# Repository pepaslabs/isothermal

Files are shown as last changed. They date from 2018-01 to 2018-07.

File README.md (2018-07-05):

# isothermal

An Arduino shield which regulates temperature.  Originally, this was used to regulate the temperature of a Hammond 1590BB.

- [schematic](kicad/releases/v1.2/isothermal.pdf)
- [gerber files](kicad/releases/v1.2)
- [OSHPark link](https://oshpark.com/shared_projects/9wWvXwMw)
- [EEVBlog discussion](http://www.eevblog.com/forum/metrology/temperature-stabilised-enclosures-heating-and-or-cooling/msg1407134/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)

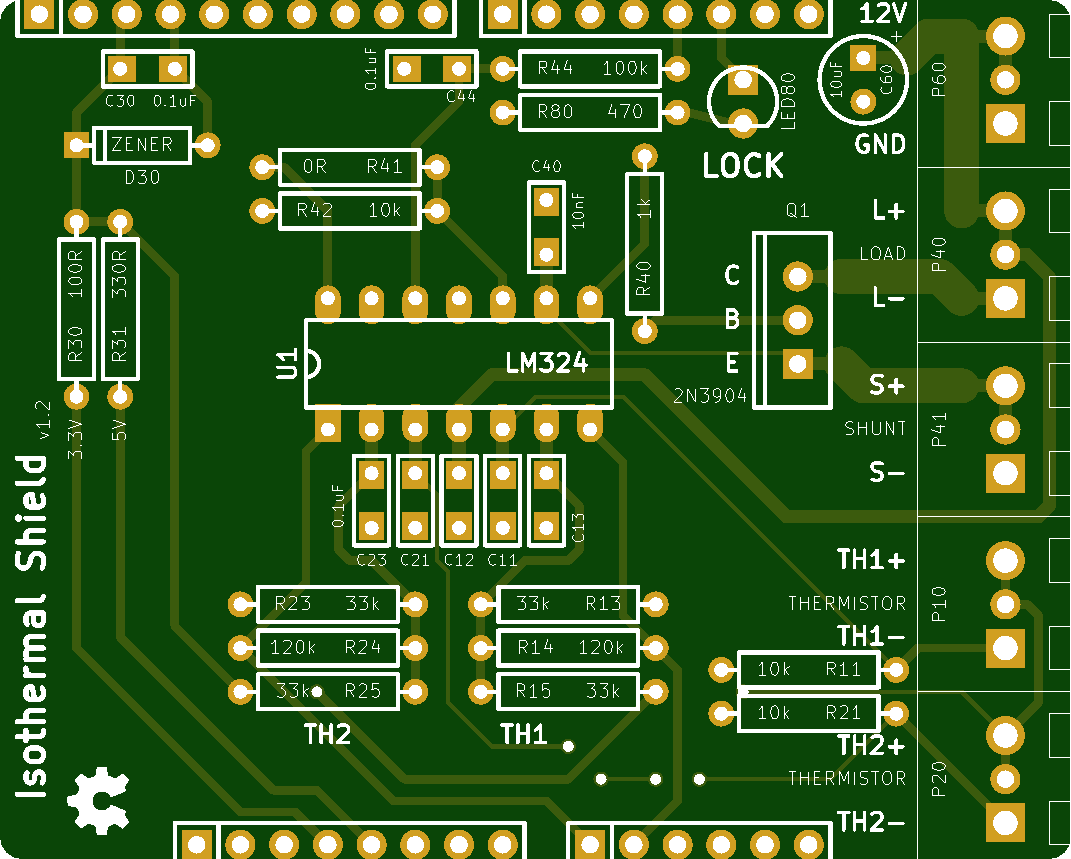
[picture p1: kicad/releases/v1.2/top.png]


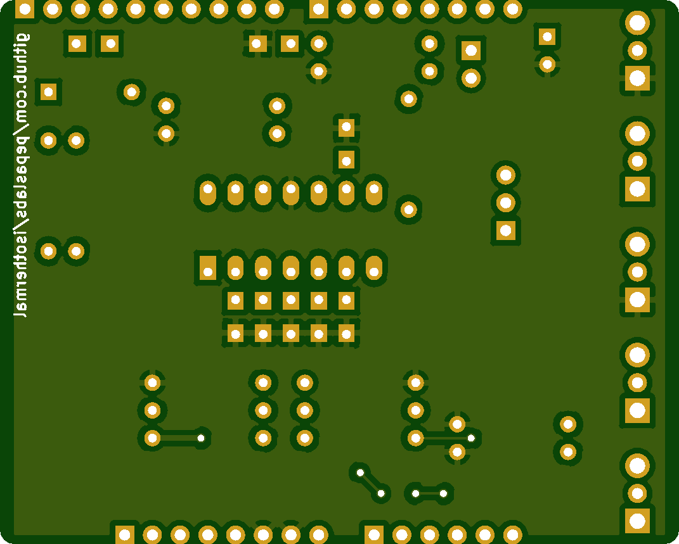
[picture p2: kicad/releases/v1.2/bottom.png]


The resistor values were chosen to map a 20C to 30C window onto (roughly) 0V to 3.3V.

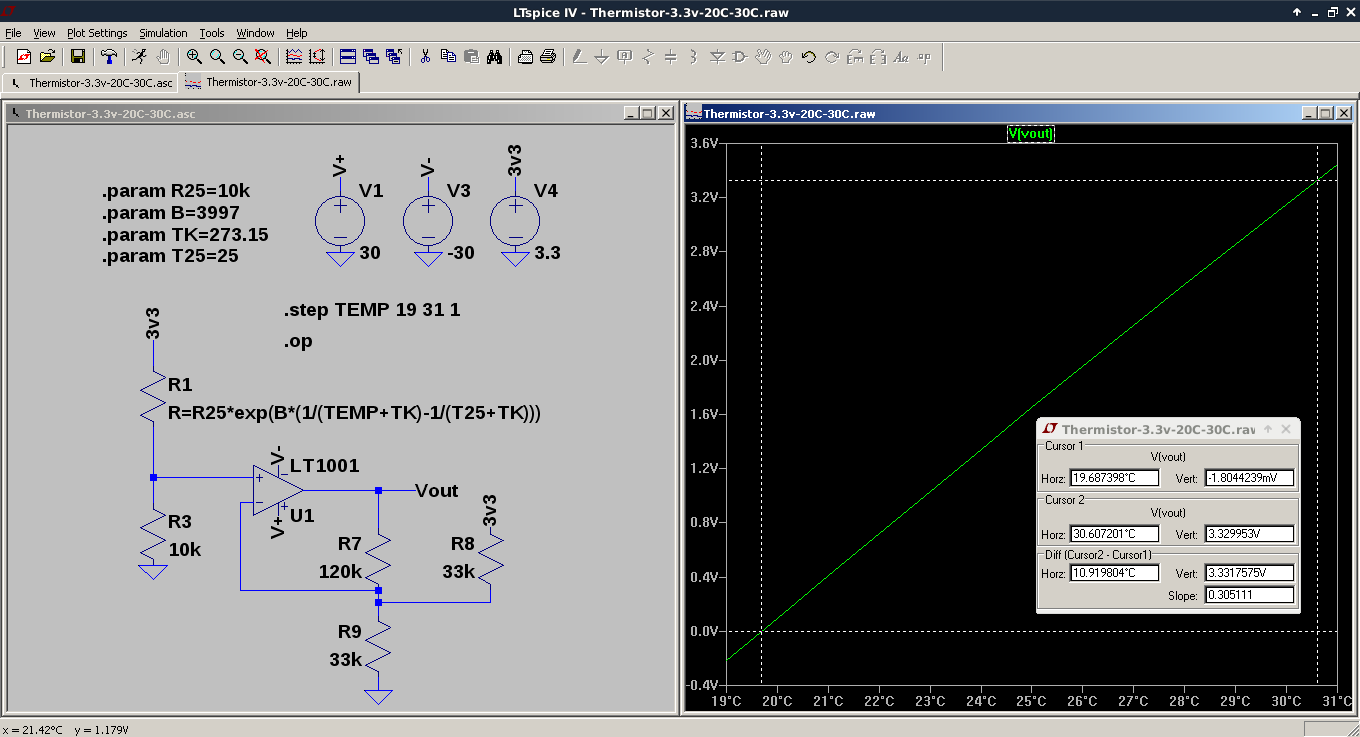
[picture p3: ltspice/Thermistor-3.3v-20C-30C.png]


See also [this link](https://github.com/cellularmitosis/logs/tree/master/20180126-25c-chamber-tuning) for PID tuning and measurements of a similar design (based on MCP9701 rather than thermistors).

## Bill of Materials (BOM)

FIXME: update this BOM for v1.2.

- (1) LM324 op amp, DIP14.
  - [Tayda](https://www.taydaelectronics.com/lm324n-lm324-324-low-power-quad-op-amp-ic.html).
- (1) 2N3904 TO-92 NPN transistor.
  - Almost any TO-92 transistor should work here.
  - [Tayda](https://www.taydaelectronics.com/t-transistors/2n-series/2n3904-npn-general-propose-transistor.html).
  - The footprint is for a TO-220, in case you need to use a bigger transistor.
- (2) 10k thermistors.
  - I use Vishay [NTCLG100E2103JB](http://www.vishay.com/docs/29050/ntclg100.pdf) which are about $1 each from [Digi-key](https://www.digikey.com/product-detail/en/vishay-bc-components/NTCLG100E2103JB/BC2531-ND/773999).
  - You could also get away with [cheap epoxy bead thermistors](https://www.taydaelectronics.com/thermistors/10k-ohm-ntc-thermistor-5mm.html), though if the Beta is different you'll need to calibrate the gain of your controller.
- 1/4W resistors, 1% metal film (precision-ish):
  - (2) 10k.
  - (4) 33k.
  - (2) 120k.
  - [Tayda](https://www.taydaelectronics.com/resistors/1-4w-metal-film-resistors/test-group-2.html).
- 1/4W resistors (non-precision):
  - (1) 100R
  - (1) 470R
    - The LED resistor -- 330R or 220R will also work.
  - (1) 1k
  - (4) 100k
  - [Tayda](https://www.taydaelectronics.com/resistors/1-4w-metal-film-resistors/test-group-2.html).
- (9) 0.1uF ceramic capacitors, through-hole or 0805.
  - [Tayda](https://www.taydaelectronics.com/capacitors/ceramic-disc-capacitors/10-x-0-01uf-50v-ceramic-disc-capacitor-pkg-of-10.html).
- (1) 10uF electrolytic capacitor, 25V, 5mm diameter, 0.1" (2.5mm) lead spacing.
  - [Tayda](https://www.taydaelectronics.com/capacitors/electrolytic-capacitors/10uf-25v-105c-radial-electrolytic-capacitor-5x11mm.html).
- (1) 3mm LED.
  - [Tayda](https://www.taydaelectronics.com/led-3mm-green.html).
- (4) 2-pole terminal block, linkable, 0.2" lead spacing.
  - [Digi-key](https://www.digikey.com/product-detail/en/on-shore-technology-inc/OSTTA024163/ED2580-ND/614529).
  - Note: don't get the cheap (ebay) ones with the phillips-head screws -- the screws are garbage and the heads will strip.  If you go cheap, get the flat-head screws.  I ordered these and they seem to do the job: https://www.ebay.com/itm/182525842695
  - I'm not sure the [Tayda](https://www.taydaelectronics.com/connectors-sockets/terminal-blocks/pcb-mount/dg300-screw-terminal-block-2-positions-5mm.html) parts will work, as they are 5mm spacing, rather than 5.08mm, which might be a problem when you link 4 of them together and expect them to fit into 0.2" holes.
- 0.1" male headers: a block of 10, 8, 8, and 6.
  - These are the Arduino pins.
  - Actually, you only need 10 pins: 3.3V, 5V, GND, GND, A0, A1, AREF, AREF's GND, D3, D2.

If you are using this to heat a Hammon 1590BB, you'll also need:
- (1) Hammond 1590BB Aluminum enclosure.
  - [Tayda](https://www.taydaelectronics.com/hardware/enclosures/1590bb-style/1590bb-style-aluminum-diecast-enclosure.html).
- 1/2W or 1W (heater) resistors.
  - (10) 10R
    - [Tayda](https://www.taydaelectronics.com/resistors/1w-metal-film-resistors/resistor-10-ohm-1w-1-metal-film-pkg-of-10.html).
- Some thermal epoxy.  Arctic Silver is easy to source.  [Walmart](https://www.walmart.com/ip/Arctic-Silver-Alumina-Premium-Ceramic-Thermal-Adhesive/20449152) has it for $6 at the moment.
- (2) "craft foam" (9x12 sheets, 6mm)
  - [Amazon](https://www.amazon.com/Bulk-Buy-Foamies-10-Pack-1199-21/dp/B00KDMQB4Y).
- Hot glue to secure the foam to the Hammond case.
- Very thin gauge wire to connect the remote thermistor.  Scrap Ethernet twisted pairs will work (26 AWG), but 30 AWG "Kynar" (wire-wrap) wire is better (less error due to heat transfer along the wire).  Thin-gauge "magnet" wire will also work.
- An Arduino.

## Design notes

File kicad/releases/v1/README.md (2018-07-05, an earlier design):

## Deprecated

Don't use this version of the board.  Use [v1.1](../v1.1) instead.

I made the spacing on the arduino pin headers a little too tight, and the holes for the terminal blocks aren't big enough to accomodate some terminal blocks.

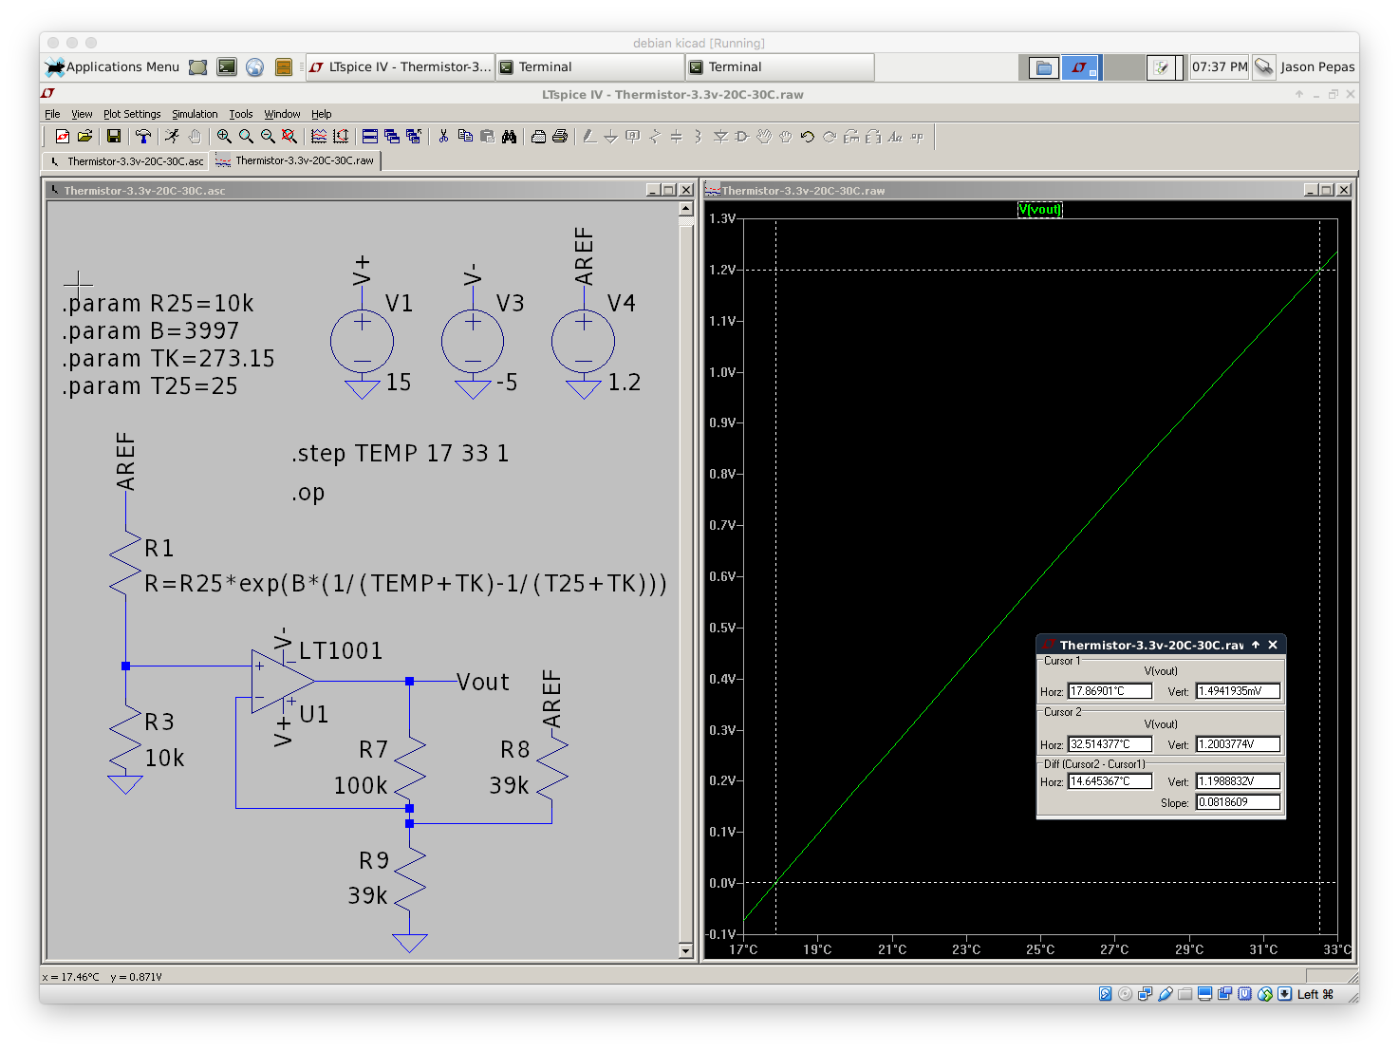
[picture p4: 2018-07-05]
ltspice/100k/scale/18C-32C-100k-39k-39k.png

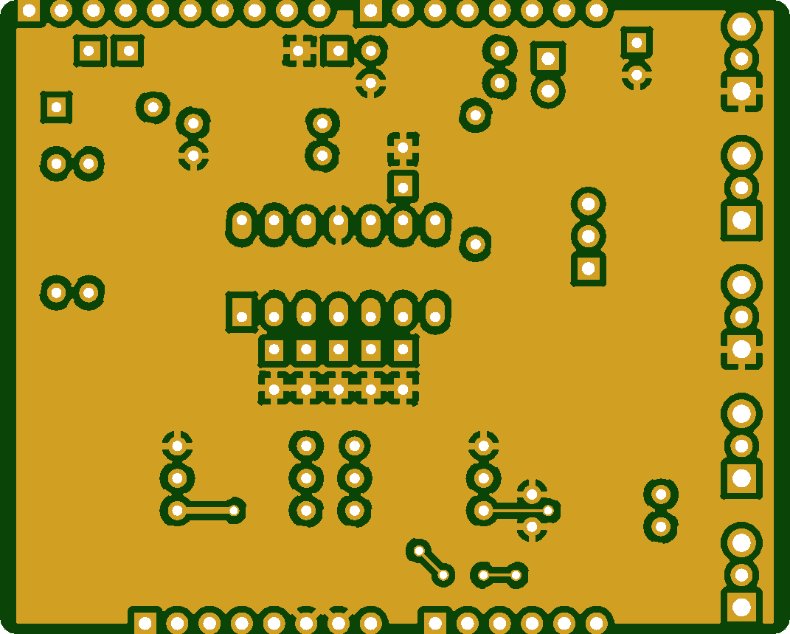
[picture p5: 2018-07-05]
kicad/releases/v1.2/bottom-copper.png

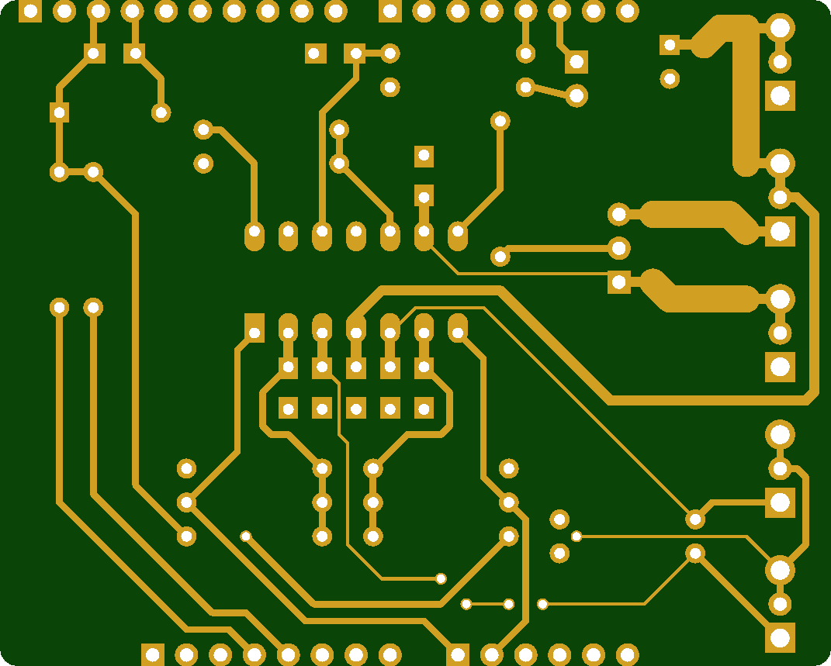
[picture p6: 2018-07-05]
kicad/releases/v1.2/top-copper.png

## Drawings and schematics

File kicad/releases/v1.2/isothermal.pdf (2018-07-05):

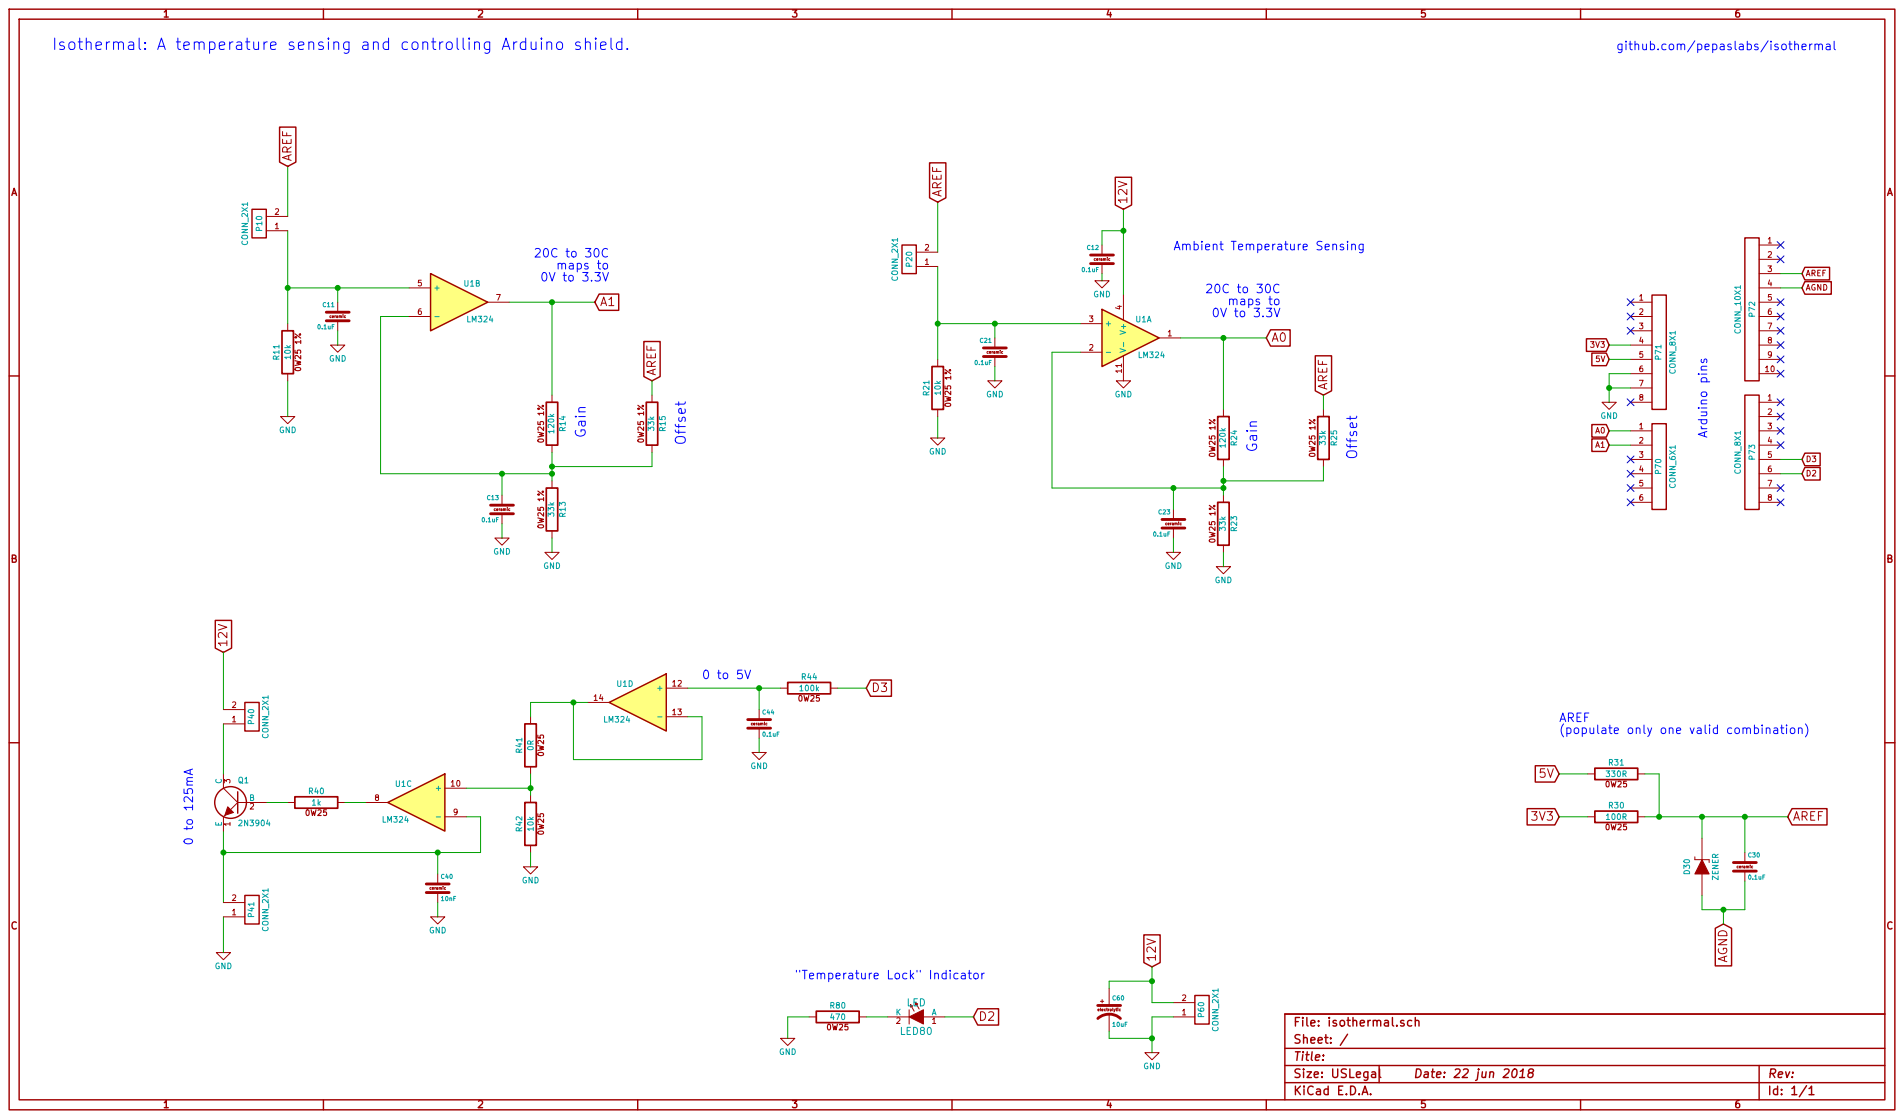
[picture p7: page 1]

(populate only one valid combination)

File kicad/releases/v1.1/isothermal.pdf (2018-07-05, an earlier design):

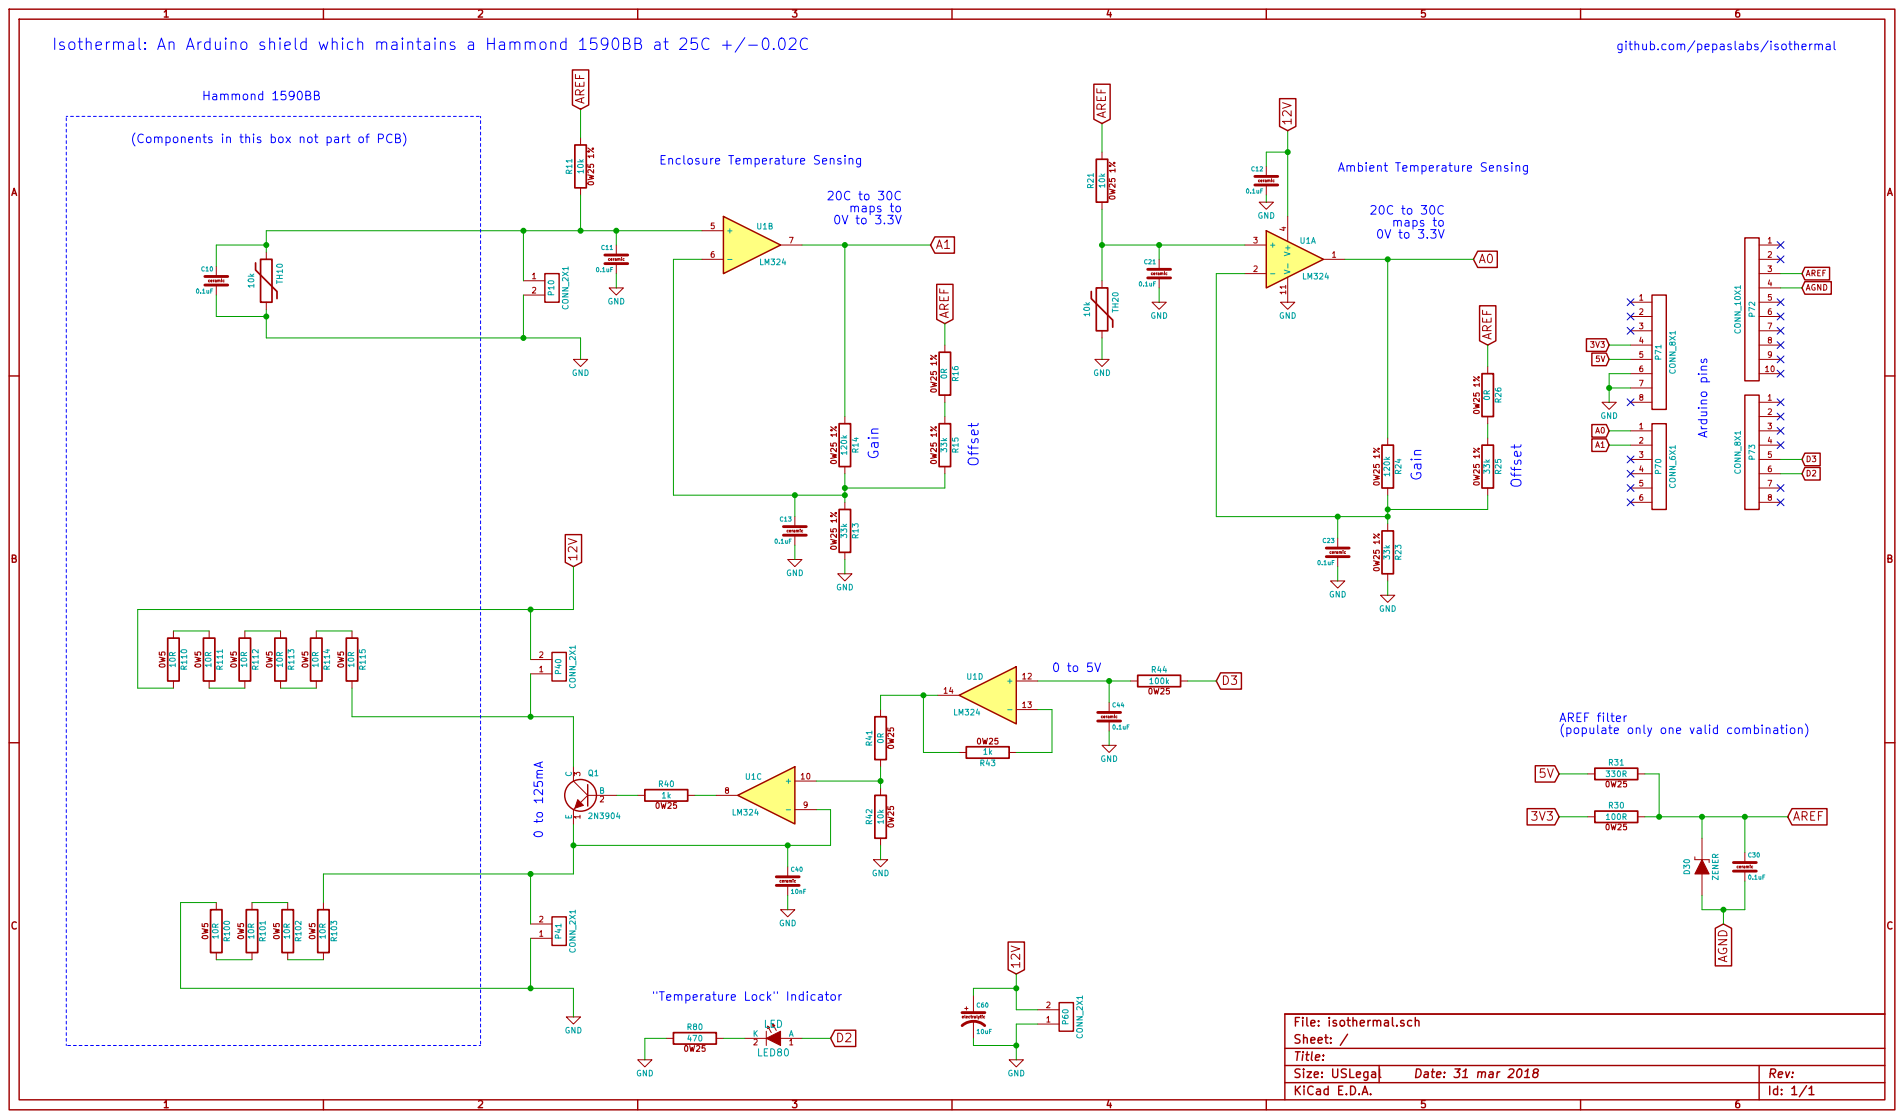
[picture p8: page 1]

(populate only one valid combination)

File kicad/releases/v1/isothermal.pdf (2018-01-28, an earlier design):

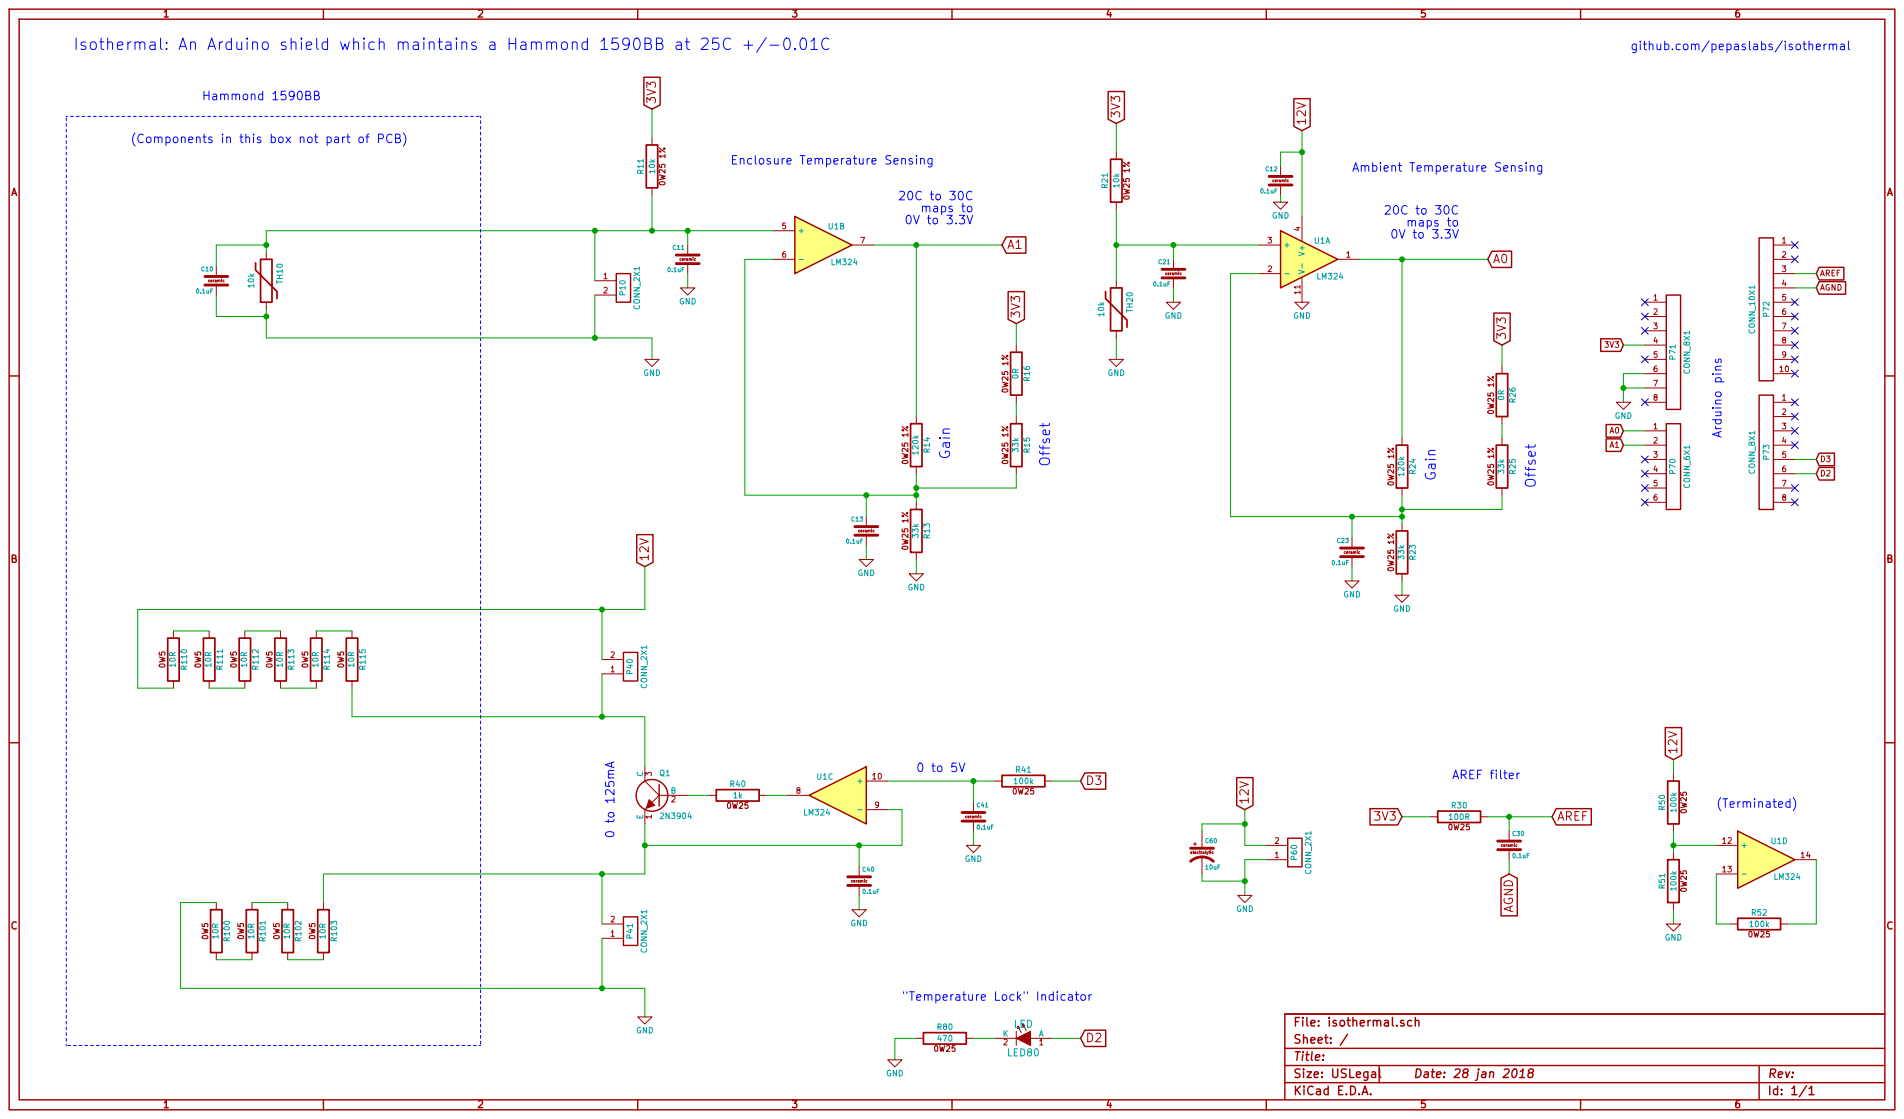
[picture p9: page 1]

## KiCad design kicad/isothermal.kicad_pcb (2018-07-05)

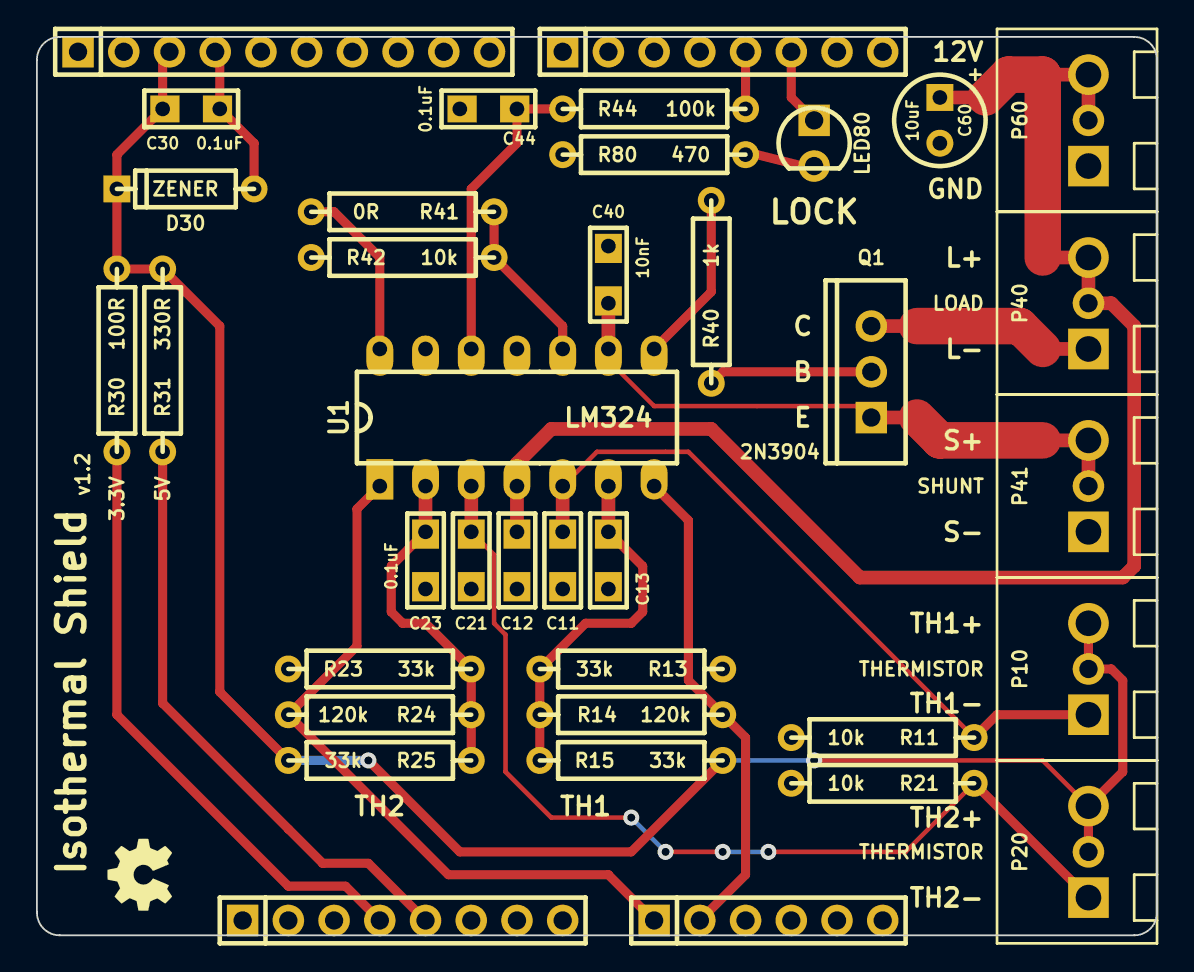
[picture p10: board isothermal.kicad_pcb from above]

Board: 2 copper layers, 62.2 x 49.9 mm, 37 parts (0 on the bottom side), 22 nets.

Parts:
C11, C12, C13, C21, C23, C30, C44: 0.1uF; CERCAP_15_059B_0805
C40: 10nF; CERCAP_15_059B_0805
C60: 10uF; ELCAP_10_20_V_059A
D30: ZENER; DIODE_SS_059A_03_PL
LED80: LED; LED_3MM_069A
P10, P20, P40, P41, P60: CONN_2X1; TERMINAL_BLOCK_2_5mm
P70: CONN_6X1; SIL-6
P71, P73: CONN_8X1; SIL-8
P72: CONN_10X1; SIL-10
Q1: 2N3904; TO-220_V_069A
R11, R21, R42: 10k; R_AXIAL_0W25_059A_PL
R13, R15, R23, R25: 33k; R_AXIAL_0W25_059A_PL
R14, R24: 120k; R_AXIAL_0W25_059A_PL
R30: 100R; R_AXIAL_0W25_059A_PL
R31: 330R; R_AXIAL_0W25_059A_PL
R40: 1k; R_AXIAL_0W25_059A_PL
R41: 0R; R_AXIAL_0W25_059A_PL
R44: 100k; R_AXIAL_0W25_059A_PL
R80: 470; R_AXIAL_0W25_059A_PL
U1: LM324; DIP14_PL

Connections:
3V3: P71.4, R30.1
5V: P71.5, R31.1
12V: C12.1, C60.1, P40.2, P60.2, U1.4
A0: P70.1, R24.2, U1.1
A1: P70.2, R14.2, U1.7
AGND: C30.2, D30.1, P72.4
AREF: C30.1, D30.2, P10.2, P20.2, P72.3, R15.2, R25.2, R30.2, R31.2
D2: LED80.1, P73.6
D3: P73.5, R44.2
GND: C11.2, C12.2, C13.2, C21.2, C23.2, C40.2, C44.2, C60.2, P41.1, P60.1, P71.6, P71.7, R11.2, R13.1, R21.2, R23.1, R42.1, R80.1, U1.11
unnamed: R41.2, U1.13, U1.14
unnamed: R41.1, R42.2, U1.10
unnamed: R40.2, U1.8
unnamed: LED80.2, R80.2
unnamed: Q1.2, R40.1
unnamed: C44.1, R44.1, U1.12
unnamed: C11.1, P10.1, R11.1, U1.5
unnamed: C13.1, R13.2, R14.1, R15.1, U1.6
unnamed: C21.1, P20.1, R21.1, U1.3
unnamed: C23.1, R23.2, R24.1, R25.1, U1.2
unnamed: P40.1, Q1.3
unnamed: C40.1, P41.2, Q1.1, U1.9

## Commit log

2018-01-28 initial release
    [isothermal-B_Cu.gbl, isothermal-B_Mask.gbs, isothermal-B_SilkS.gbo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]
2018-01-28 board shots
2018-03-31 increasing terminal block hole size, fixing pin spacing
    [isothermal-B_Cu.gbl, isothermal-B_Mask.gbs, isothermal-B_SilkS.gbo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]
2018-04-28 adding ptf56 resistor ltspice calculation
2018-06-08 adding additional resistor calculations
